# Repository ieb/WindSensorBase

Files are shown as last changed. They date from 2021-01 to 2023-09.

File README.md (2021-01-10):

# WindSensor Base 

Reads data transmitted on 2.4GHz RF from a windsensor device and converts it into NMEA2000 Wind sentences for use on a NMEA2000 bus. The RF uses JDY-40 modules https://www.electrodragon.com/w/images/0/05/EY-40_English_manual.pdf based on a BEKEN RF Chip https://www.mikrocontroller.net/attachment/381910/BT-WiFi-52rf5541.pdf. Which claims a range of upto 120M (tested through walls and metal roofing at 40M no problems). The Base uses a ESP32 module (WROOM) with Wifi and BT disabled consuming about 80mA at 5V. CAN transcevers are MCP2562FD chips using 3.3V logic levels and 5V CAN driver voltage which seems to be compatible with most marine equipment expecting CANH at arround 4.5v.

The same setup could be used for any other RF Serial -> CANBus sensor, and the JDY-40 can switch RF channels relatively quickly, however for this application probably not fast enough to bridge Wind Readings at 10Hz. Reading data at 9600 1 line every 0.1s on a fixed RF channel works no problem as the underlying RF transport runs at 2Mb/s, but the JDY-40 wont switch reliably between channels using AT commands, see the doc on the ED-40 manual.

# TODO

[ ] Implement CLI with configuration settings.
[ ] Test on NMEA2000 bus

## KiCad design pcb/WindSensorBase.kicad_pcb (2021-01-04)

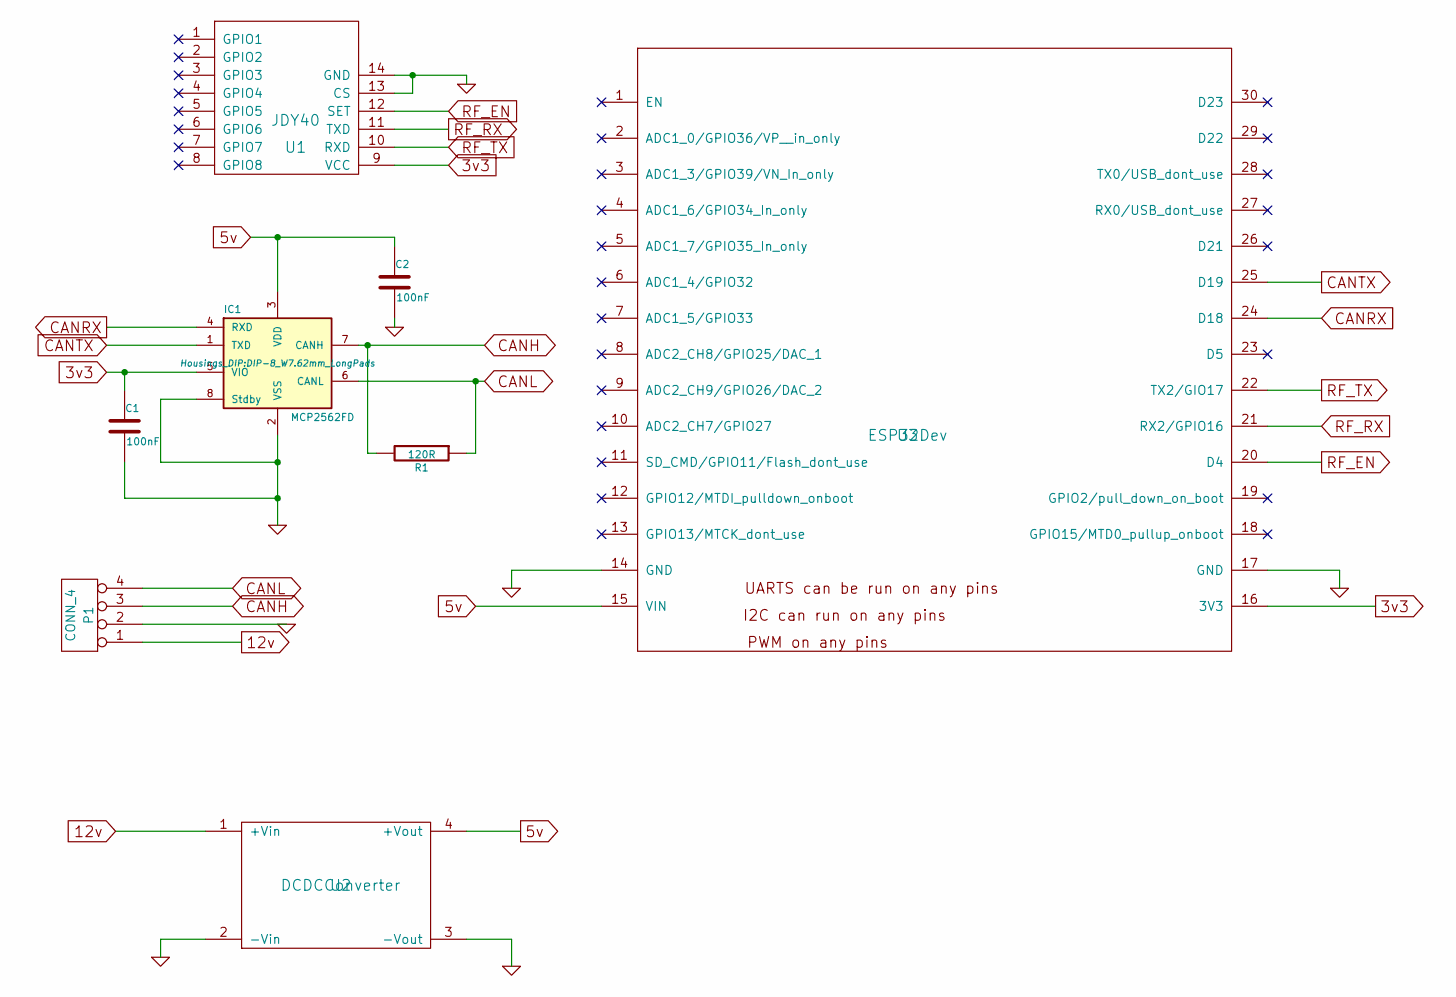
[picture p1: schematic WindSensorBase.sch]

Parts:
C1, C2: 100nF; C_Disc_D6_P5
IC1: MCP2562FD; DIP-8_W7.62mm_LongPads
P1: CONN_4; Pin_Header_Angled_1x04_Pitch2.54mm
R1: 120R; Resistor_Horizontal_RM7mm
U1: JDY40; JDY-40-TH
U2: DCDCConverter; DC-DC-Converter
U3: ESP32Dev; DIP-30_1_ELL

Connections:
3v3: C1.1, IC1.5 (VIO), U1.9 (VCC), U3.16 (3V3)
5v: C2.1, IC1.3 (VDD), U2.4 (+Vout), U3.15 (VIN)
12v: P1.1, U2.1 (+Vin)
CANH: IC1.7 (CANH), P1.3, R1.2
CANL: IC1.6 (CANL), P1.4, R1.1
CANRX: IC1.4 (RXD), U3.24 (D18)
CANTX: IC1.1 (TXD), U3.25 (D19)
GND: C1.2, C2.2, IC1.2 (VSS), IC1.8 (Stdby), P1.2, U1.13 (CS), U1.14 (GND), U2.2 (-Vin), U2.3 (-Vout), U3.14 (GND), U3.17 (GND)
RF_EN: U1.12 (SET), U3.20 (D4)
RF_RX: U1.11 (TXD), U3.21 (RX2/GPIO16)
RF_TX: U1.10 (RXD), U3.22 (TX2/GIO17)

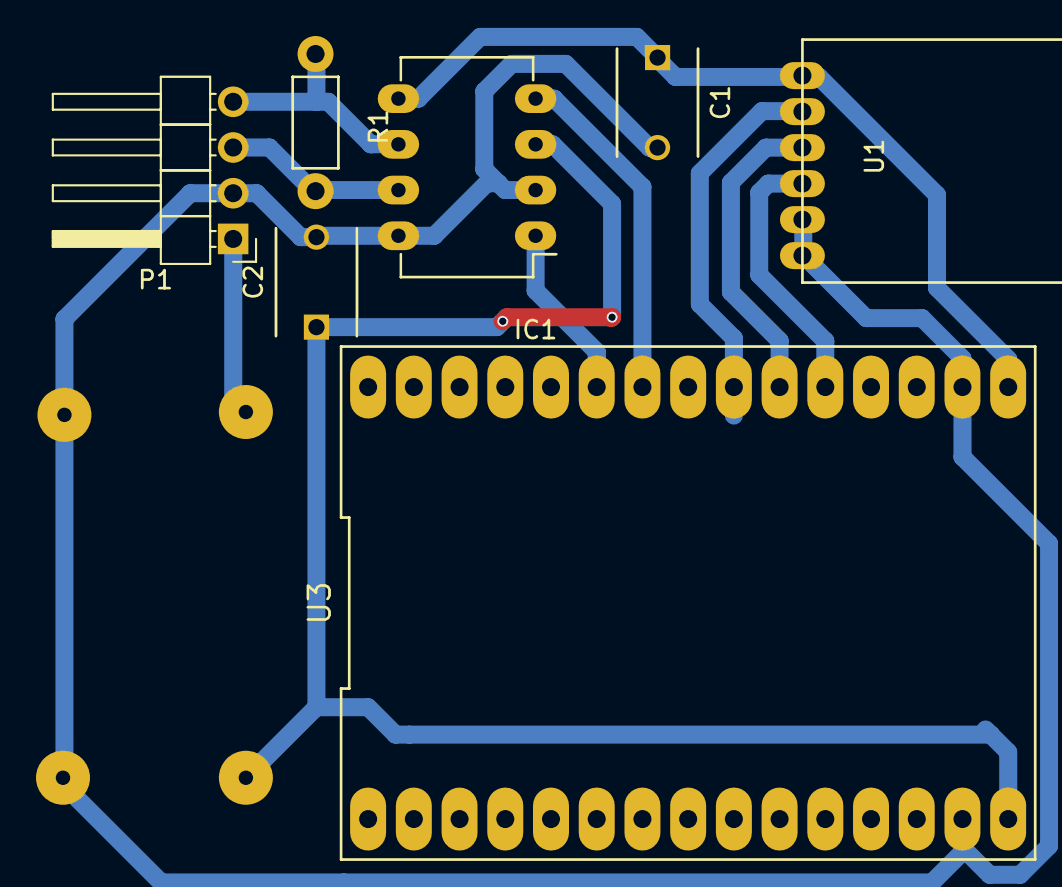
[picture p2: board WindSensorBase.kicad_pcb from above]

Board: 2 copper layers, 8 parts (1 on the bottom side), 11 nets.

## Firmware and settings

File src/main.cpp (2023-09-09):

#include <Arduino.h>

//#define SERIAL_DEBUG_DISABLED

#define USE_LIB_WEBSOCKET true
#define ESP32_CAN_TX_PIN GPIO_NUM_19
#define ESP32_CAN_RX_PIN GPIO_NUM_18

#define DATAEN_PIN GPIO_NUM_4
#define RF_RX  GPIO_NUM_16
#define RF_TX  GPIO_NUM_17
#define BT_INDICATOR_PIN GPIO_NUM_2
#define BT_ENABLE_PIN GPIO_NUM_25 

#include <NMEA2000_esp32.h>
#include <NMEA2000_CAN.h> 
#include <N2kMessages.h>


#include <jdy40.h>
#include <windsensor.h>
#include <windconfig.h>


#define BLUETOOTHCLASSIC 1
#ifdef BLUETOOTHCLASSIC
#include <BlueToothSerial.h>
BluetoothSerial SerialBT;
#define SerialIO SerialBT
#else
#define SerialIO Serial
#endif


const unsigned long TransmitMessages[] PROGMEM={130306L,0};



Jdy40 jdy40(DATAEN_PIN);
WindSensor windSensor(&SerialIO);
WindConfig windConfig(&windSensor,&SerialIO);

#define INPUT_BUFFER_SIZE 1024
char inputBuffer[INPUT_BUFFER_SIZE];


int blueToothRunning = false;

void StopBluetooth() {
#ifdef BLUETOOTHCLASSIC      
  if ( blueToothRunning ) {
    SerialBT.end();
    digitalWrite(BT_INDICATOR_PIN, LOW); 
    blueToothRunning = false;
  }
#endif
}

void CheckBluetooth() {
#ifdef BLUETOOTHCLASSIC      
  if ( !blueToothRunning ) {
    if ( true || digitalRead(BT_ENABLE_PIN) == LOW ) {
      SerialBT.begin("WindMonitor"); 
      blueToothRunning = true;
      digitalWrite(BT_INDICATOR_PIN, HIGH); 
    }
  }
#endif
}


void setup() {

#ifdef BLUETOOTHCLASSIC        
  pinMode(BT_ENABLE_PIN, INPUT_PULLUP); 
  pinMode(BT_INDICATOR_PIN, OUTPUT);
  digitalWrite(BT_INDICATOR_PIN, LOW); 
  CheckBluetooth();
#endif

  Serial.begin(115200);
  Serial.println("Confgiure JDY40");

  Serial1.begin(9600,SERIAL_8N1, RF_RX, RF_TX);
  
  jdy40.setInputBuffer(inputBuffer, INPUT_BUFFER_SIZE);
  jdy40.setDebug(&Serial);
  jdy40.begin(&Serial1, 9600);
  jdy40.startConfig();
  jdy40.init();

  jdy40.setRFID(1021);
  jdy40.setDeviceID(1123);
  jdy40.setChannel(1);

  windConfig.begin();

  // Setup NMEA2000
  // Set Product information
  NMEA2000.SetProductInformation("00000002", // Manufacturer's Model serial code
                                 100, // Manufacturer's product code
                                 "Simple wind monitor",  // Manufacturer's Model ID
                                 "1.1.0.22 (2016-12-31)",  // Manufacturer's Software version code
                                 "1.1.0.0 (2016-12-31)" // Manufacturer's Model version
                                 );
  // Set device information
  NMEA2000.SetDeviceInformation(1, // Unique number. Use e.g. Serial number.
                                130, // Device function=Atmospheric. See codes on http://www.nmea.org/Assets/20120726%20nmea%202000%20class%20&%20function%20codes%20v%202.00.pdf
                                85, // Device class=External Environment. See codes on  http://www.nmea.org/Assets/20120726%20nmea%202000%20class%20&%20function%20codes%20v%202.00.pdf
                                2085 // Just choosen free from code list on http://www.nmea.org/Assets/20121020%20nmea%202000%20registration%20list.pdf                               
                               );

#ifdef DEBUG_NMEA2000
  // debugging with no chips connected.
  NMEA2000.SetForwardStream(&SerialIO);
  NMEA2000.SetForwardType(tNMEA2000::fwdt_Text); 
  NMEA2000.SetDebugMode(tNMEA2000::dm_ClearText); // Uncomment this, so you can test code without CAN bus chips on Arduino Mega
#endif  

  // this is a node, we are not that interested in other traffic on the bus.
  NMEA2000.SetMode(tNMEA2000::N2km_NodeOnly,24);
  NMEA2000.EnableForward(false);
  NMEA2000.ExtendTransmitMessages(TransmitMessages);
  NMEA2000.Open();

  

  Serial.println("Starting");
  
}

// todo, configuration.

#define WindUpdatePeriod 1000

void SendN2kWind() {
  static unsigned long WindUpdated=millis();
  tN2kMsg N2kMsg;

  if ( millis()-WindUpdated > WindUpdatePeriod ) {
    SetN2kWindSpeed(N2kMsg, 1, windSensor.getWindSpeed(), windSensor.getWindAngle() ,N2kWind_Apprent);
    WindUpdated=millis();
    NMEA2000.SendMsg(N2kMsg);
  }
}

void DumpStatus() {
    SerialIO.printf("WindSpeed               = %f m/s  %f kn\n", windSensor.getWindSpeed(), windSensor.getWindSpeed()*1.94384);
    SerialIO.printf("WindAngle               = %f rad  %f deg\n", windSensor.getWindAngle(), (windSensor.getWindAngle()*360)/(2.0*3.14159));
    SerialIO.printf("Packets Read            = %ld\n", windSensor.getPacketsRead());
    SerialIO.printf("Packets Errors          = %ld\n", windSensor.getErrors());
    SerialIO.printf("CRC Errors              = %d\n", jdy40.getCRCErrors());
    SerialIO.printf("Silence Periods         = %ld\n", windSensor.getPacketsDropped());
    SerialIO.printf("Average Period          = %f ms\n", 0.01*(double)(windSensor.getSumReadPeriod()));
} 


void CallBack(int8_t cmd) {
  switch(cmd) {
    case CMD_STATUS:
      DumpStatus();
      break;
    case CMD_BT_OFF:
      StopBluetooth();
      break;
  }
}


void loop() {
  // read the serial data and process.
  CheckBluetooth();
  windConfig.process(CallBack);
  windSensor.processData(jdy40.readLine(), windConfig.isMonitoringEnabled());
  // Send to N2K Bus
  SendN2kWind();
  NMEA2000.ParseMessages();
}

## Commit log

2021-01-19 Switched to configuration over bT, may cause problems on 2.4GHz
    [main.cpp]
2023-09-09 Fixed 49day overflows
    [WindSensorBase.kicad_pcb, WindSensorBase.sch, _saved_WindSensorBase.sch]
